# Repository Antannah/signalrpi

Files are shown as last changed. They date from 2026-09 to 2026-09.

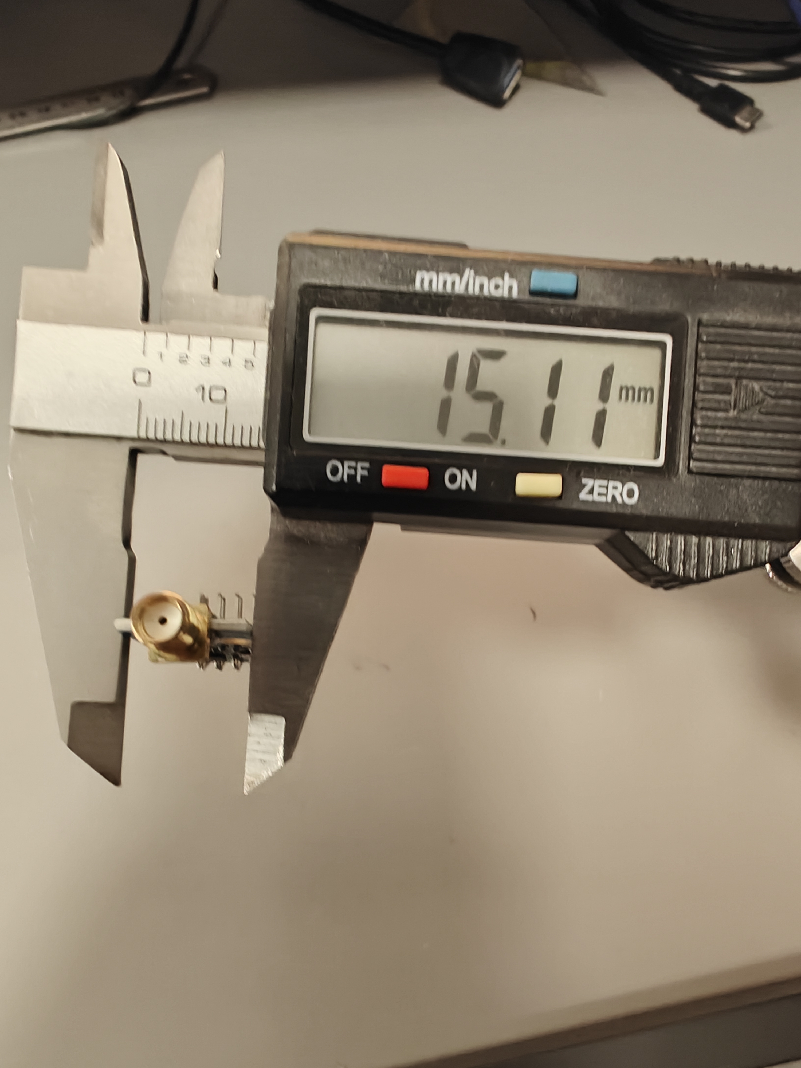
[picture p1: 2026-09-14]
doc/ebyte-07-m1101-sma_width.jpg

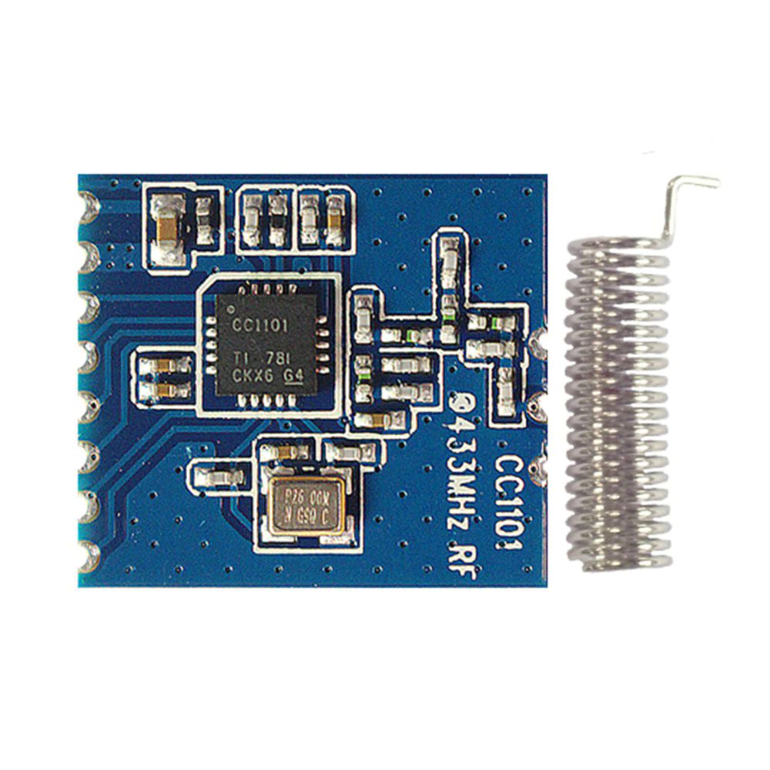
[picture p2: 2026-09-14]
doc/CC1101-433MHz-CC1101-433.png

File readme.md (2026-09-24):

# signalrpi: RF-Empfänger für Smart-Home-Komponenten (433 & 868 MHz)

Dieses Projekt realisiert einen softwarebasierten Funkempfänger für die Frequenzbänder **433 MHz** (LPD-Band) und **868 MHz** (SRD-Band) (im Kontext oft als 443 und 886 MHz referenziert). Die Hardware-Basis bildet ein **RP2040**-Microcontroller (z. B. Raspberry Pi Pico oder Pico W), an den zwei **CC1101**-Transceiver-Module direkt über SPI angebunden sind. Die Dekodierungslogik wird aus dem Open-Source-Projekt **SignalDUINO** portiert. Die dekodierten Daten oder Pulse werden über ein strukturiertes **MQTT-Protokoll** zur weiteren Verarbeitung bereitgestellt.

---

## 1. Systemarchitektur & Hardware-Topologie

Die zeitkritische Erfassung der Signalflanken (im Bereich von $100\,\mu\text{s}$ bis $1000\,\mu\text{s}$) wird direkt auf dem RP2040-Microcontroller ausgeführt. Durch die Nutzung der programmierbaren I/O-Blöcke (**PIO**) des RP2040 können die Puls- und Pausendauern deterministisch und jitterfrei erfasst werden, ohne die CPU-Kerne zu belasten.

```mermaid
graph TD
    RF433[433 MHz CC1101 Links] -->|GDO0 Pin GP6| PIO0[RP2040: PIO State Machine 0]
    RF868[868 MHz CC1101 Rechts] -->|GDO0 Pin GP21| PIO1[RP2040: PIO SM1 / FSK FIFO]
    
    RF433 <-->|SPI1 GP10-12| SPI1[RP2040: SPI1 Controller]
    RF868 <-->|SPI0 GP16/18/19| SPI0[RP2040: SPI0 Controller]
    
    PIO0 -->|Pulse Durations| CPU[RP2040: CPU Core 0/1]
    PIO1 -->|Pulse / FSK Bytes| CPU
    
    CPU -->|JSON Payloads| Comm[RP2040: WiFi CYW43439]
    Comm -->|MQTT / TCP| Broker[MQTT Broker]
```
 
### 1.1 Pin-Belegung (RP2040 zu 2× CC1101 via getrennten SPI-Bussen)

Die beiden CC1101-Module nutzen zwei **getrennte Hardware-SPI-Controller** des RP2040 (SPI1 auf der linken Pinleiste, SPI0 auf der rechten Pinleiste). Dadurch werden Buskollisionen und kapazitive Lasten auf den Leitungen vermieden.

#### Modul 1: 433 MHz Transceiver (Links, SPI1)
| CC1101 Funktion | Aderfarbe | RP2040 Pin (physisch) | RP2040 GPIO | Beschreibung |
| :--- | :--- | :--- | :--- | :--- |
| **VCC** | **Rot (rt)** | **Pin 36** | `3V3(OUT)` | Spannungsversorgung (3.3 V) |
| **GND** | **Braun (bn)** | **Pin 13** (oder 18) | `GND` | Masse |
| **SCK** | **Gelb (ge)** | **Pin 14** | `GP10 (SPI1 SCK)` | SPI Clock |
| **MOSI (SI)** | **Orange (or)** | **Pin 15** | `GP11 (SPI1 TX)` | SPI Data In (Modul) / Out (Pico) |
| **MISO (SO)** | **Grün (gn)** | **Pin 16** | `GP12 (SPI1 RX)` | SPI Data Out (Modul) / In (Pico) |
| **CSn** | **Lila (li)** | **Pin 17** | `GP13` | Chip Select Modul 1 |
| **GDO0** | **Blau (bl)** | **Pin 9** | `GP6` | Demoduliertes Signal (PIO SM0 Flankenerkennung) |
| *(GDO2)* | *(Grau/frei)* | **Pin 10** | `GP7` | Optional / Reserve |

#### Modul 2: 868 MHz Transceiver (Rechts, SPI0)
| CC1101 Funktion | Aderfarbe | RP2040 Pin (physisch) | RP2040 GPIO | Beschreibung |
| :--- | :--- | :--- | :--- | :--- |
| **VCC** | **Rot (rt)** | **Pin 36** | `3V3(OUT)` | Spannungsversorgung (3.3 V) |
| **GND** | **Braun (bn)** | **Pin 23** (oder 28/38) | `GND` | Masse |
| **MISO (SO)** | **Grün (gn)** | **Pin 21** | `GP16 (SPI0 RX)` | SPI Data Out (Modul) / In (Pico) |
| **CSn** | **Lila (li)** | **Pin 22** | `GP17` | Chip Select Modul 2 |
| **SCK** | **Gelb (ge)** | **Pin 24** | `GP18 (SPI0 SCK)` | SPI Clock |
| **MOSI (SI)** | **Orange (or)** | **Pin 25** | `GP19 (SPI0 TX)` | SPI Data In (Modul) / Out (Pico) |
| **GDO0** | **Blau (bl)** | **Pin 27** | `GP21` | Signal/Sync (PIO SM1 bei OOK oder FSK-Trigger) |
| *(GDO2)* | *(Grau/frei)* | **Pin 26** | `GP20` | Optional / Reserve |

#### Einheitliche Kabelfarbkodierung (beide Stränge)
* **VCC:** Rot (`rt`)
* **GND:** Braun (`bn`)
* **MOSI (SI):** Orange (`or`)
* **SCLK:** Gelb (`ge`)
* **MISO (SO):** Grün (`gn`)
* **GDO0:** Blau (`bl`)
* **CSn:** Lila (`li`)

#### Pufferkondensator-Konzept (bei ca. 15 cm Leitungslänge)
* **Zentraler Puffer:** $1\times 100\,\mu\text{F}$ Elektrolytkondensator direkt am Pico W zwischen `3V3(OUT)` (Pin 36) und `GND`.
* **Lokale HF-Entkopplung:** Je $1\times 10\,\mu\text{F}$ Keramikkondensator (MLCC X7R/X5R) direkt an den VCC/GND-Pins der beiden CC1101-Module am Leitungsende.

---

## 2. Frequenzbänder und HF-Modulation

Die Sensoren und Aktoren im Heimautomatisierungsbereich nutzen primär folgende Spezifikationen:

| Parameter | 433 MHz Band | 868 MHz Band |
| :--- | :--- | :--- |
| **Effektive Frequenz** | ~433.92 MHz | ~868.30 MHz |
| **Modulation** | ASK / OOK (Amplitude Shift Keying / On-Off Keying) | ASK / OOK oder FSK (Frequency Shift Keying) |
| **Typische Geräte** | Intertechno, Baumarkt-Steckdosen, Wettersensoren | MAX!, LaCrosse, HomeMatic, EQ3 |
| **Hardware-Modul** | CC1101 (konfiguriert für 433 MHz) | CC1101 (konfiguriert für 868 MHz) |

---

## 3. Funktionale Komponentenbeschreibung

Das System ist funktional in drei getrennte, sequenzielle Verarbeitungsschritte unterteilt, um eine saubere Trennung zwischen Hardware-nahem Signalempfang, logischer Dekodierung und der Verteilung der Daten zu gewährleisten.

```mermaid
graph LR
    CC1101[CC1101 Transceiver] -->|Demoduliertes Signal| Comp1[1. Signalempfang & Flankenerkennung]
    Comp1 -->|Puls-Pausen-Folge in µs| Comp2[2. Protokolldekodierung]
    Comp2 -->|Strukturierte Sensordaten| Comp3[3. MQTT-Dispatcher]
    Comp3 -->|JSON via TCP/IP| Broker[MQTT Broker]
```

---

### 3.1 Komponente 1: Empfang & Flankenerkennung (Hardware-nahe Ebene)

Diese Komponente läuft direkt auf dem **RP2040-Microcontroller**. Ihre Hauptaufgabe ist die zeitlich hochpräzise Erfassung der Phasenwechsel des demodulierten Signals am CC1101 GDO0-Pin.

#### 1. Signal-Akquisition & Demodulation (CC1101)
*   Das CC1101-Modul wird über SPI so konfiguriert, dass es das HF-Signal demoduliert (ASK/OOK oder FSK) und das binäre Basisbandsignal (High/Low) auf den GDO0-Pin legt.
*   Es erfolgt keine hardwareseitige Paketfilterung; es wird der rohe Bitstream (einschließlich Rauschen im Äther) ausgegeben.

#### 2. Jitterfreie Flankenerkennung mittels PIO (Programmable I/O)
*   Ein PIO-Programm überwacht den GPIO-Pin des GDO0-Eingangs in einer Schleife mit konstanter Taktrate (z. B. 1 MHz für eine Auflösung von $1\,\mu\text{s}$).
*   **Ablauf im PIO-Zustandsautomaten:**
    1. Warte auf Zustandsänderung (Flanke) am Pin.
    2. Wenn Flanke auftritt: Übertrage den aktuellen Zählerstand (Dauer der vorherigen Phase in $\mu\text{s}$) in die RX-FIFO des RP2040.
    3. Setze den internen Zähler zurück und beginne mit der Messung der nächsten Phase.
*   **Vorteil:** Dieses Verfahren ist deterministisch und unabhängig vom CPU-Scheduling oder Interrupt-Latenzen des Microcontrollers.

#### 3. Rauschunterdrückung & Paketabgrenzung (Software-Filterung)
*   **Glitch-Filter:** Phasen, die kürzer als eine minimale Pulsdauer sind (z. B. $< 50\,\mu\text{s}$), werden als Rauschen verworfen.
*   **Paketabgrenzung (Inter-Packet Gap):** Wenn der Pin für eine definierte Zeit (z. B. $> 5000\,\mu\text{s}$) auf einem konstanten Pegel (meist Low/Pause) bleibt, wird dies als Ende eines Datenpakets interpretiert. Die bis dahin gesammelte Puls-Pausen-Folge (ein Array aus ganzzahligen Werten in $\mu\text{s}$) wird zur Dekodierung freigegeben.

---

### 3.2 Komponente 2: Dekodierung der Signalfolgen (Mustererkennung & Protokoll-Parser)

Diese Komponente nimmt die rohe Puls-Pausen-Folge entgegen und wandelt sie in ein logisches Bit-Muster um, welches anschließend physikalisch interpretiert wird. Hierbei kommt die bewährte **SignalDUINO-Mustererkennung (`signalDecoder.cpp`)** zum Einsatz:

```mermaid
flowchart TD
    Raw["Rohe Pulsfolge (µs)"] --> PD["PatternDecoder (Mustererkennung)"]
    PD -->|"Basis-Clock T0 (z.B. 380 µs) + diskrete Vielfache [1, 3, 1, 3, 3, 1, ...]"| Decoders{"OOK-Decoder Pipeline"}
    Decoders -->|"Tri-State / Drehschalter-Code"| IT["Intertechno Decoder (V1 & V3)"]
    Decoders -->|"PWM 36-Bit Klima"| TCM["TCM97001 (NC_WS)"]
    Decoders -->|"PWM 48-Bit Bodenfeuchte"| WS["SD_WS_50"]
    Decoders -->|"Unbekanntes Muster"| Live["Live-Sniffer / Rohdaten-Export"]
```

#### 1. Dynamische Takt- und Vielfachen-Erkennung (`PatternDecoder`)
*   **Clusterung:** Bildet adaptive Cluster ähnlicher Pulslängen mit $\pm 25\%$ Toleranzband.
*   **Basis-Takt ($T_0$ / Clock):** Findet die kürzeste signifikant häufige Pulsdauer (typischerweise $10 - 15\%$ aller Pulse, z. B. $380\,\mu\text{s}$).
*   **Diskrete Vielfache:** Alle Pulse werden als ganzzahlige Vielfache quantisiert: $k_i = \text{round}(P_i / T_0)$. Dadurch sind nachgelagerte Decoder immun gegen Taktjitter und Quarzdriften.

#### 2. Protokoll-Matching & Toleranzabgleich
Die quantisierten Vielfachen werden der Kette registrierter Decoder übergeben:
*   *Tri-State Modulation:* $1T / 3T + 1T / 3T \rightarrow$ `'0'`, $1T / 3T + 3T / 1T \rightarrow$ `'F'`, $3T / 1T + 3T / 1T \rightarrow$ `'1'`, $3T / 1T + 1T / 3T \rightarrow$ `'D'`.
*   *Manchester-Codierung:* Phasenübergänge (z. B. $1T / 1T / 1T / 5T$ vs. $1T / 5T / 1T / 1T$ bei Intertechno V3).
*   *Pulsweitenmodulation (PWM):* Längenverhältnisse von High- und Low-Phasen (z. B. $1T$ High + $4T/8T$ Low bei TCM97001).

---

### 3.3 Komponente 3: MQTT-Dispatcher & Gateway (Verteilungs-Ebene)

Diese Komponente bereitet die physikalischen Daten für die Heimautomatisierung auf und sorgt für den zuverlässigen Transport über das Netzwerk.

#### 1. Payload-Strukturierung (JSON)
Die extrahierten Werte werden in eine standardisierte, maschinenlesbare JSON-Struktur überführt. Neben den Nutzdaten werden Metadaten (Zeitstempel, Signalstärke RSSI, Protokollname) angehängt, um eine lückenlose Diagnose zu ermöglichen.

#### 2. Topic-Struktur & Publish-Strategie
Die Topics sind hierarchisch aufgebaut, um eine einfache Filterung im MQTT-Broker (z. B. durch Wildcards) zu ermöglichen:
*   **Statustopic:** `signalrpi/status` (LWT - Last Will and Testament zur Verbindungsüberwachung)
*   **Raw-Topic (Debugging):** `signalrpi/raw` (Übertragung von Roh-Pulsdaten bei unbekannten Protokollen)
*   **Datentopic:** `signalrpi/messages/<protocol>/<device_id>`

#### 3. JSON-Payload-Spezifikation (Beispiel Wettersensor - Protokoll SD_WS07)
**Topic:** `signalrpi/messages/SD_WS07/sensor_ch1`
```json
{
  "timestamp": "2026-06-24T16:22:04Z",
  "protocol": "SD_WS07",
  "device_id": "sensor_ch1",
  "data": {
    "temperature": 21.4,
    "humidity": 55.0,
    "battery_low": false
  },
  "signal": {
    "rssi": -72.0,
    "pulses": 36
  }
}
```

#### 4. Integration in FHEM (via MQTT2)

FHEM-Benutzer können SignalRPI über das moderne `MQTT2`-Subsystem anbinden. Da SignalRPI standardisierte JSON-Payloads und native Status-Topics verwendet, ist kein eigener SignalDUINO-USB-Stick mehr am FHEM-Host nötig.

##### A. Broker-Verbindung herstellen (FHEM)
Falls FHEM noch nicht mit dem Mosquitto-Broker verbunden ist:
```perl
define myBroker MQTT2_CLIENT 192.168.125.4:1883
attr myBroker clientId fhem_signalrpi
attr myBroker keepalive 60
attr myBroker autocreate simple
```

##### B. Eingerichteten Sensor einbinden (`MQTT2_DEVICE`)
SignalRPI sendet Sensordaten zyklisch auf `signalrpi/devices/<ha_id>/state`. Über die FHEM-Funktion `json2nameValue($EVENT)` werden die JSON-Attribute automatisch in diskrete FHEM-Readings zerlegt:
```perl
define Blumentopf MQTT2_DEVICE
attr Blumentopf IODev myBroker
attr Blumentopf readingList signalrpi/devices/blumentopf/state:.* { json2nameValue($EVENT) }
attr Blumentopf stateFormat Feuchte: moisture % | Bat: battery_voltage V | RSSI: rssi dBm
```
*Erzeugte FHEM-Readings:* `moisture`, `battery_voltage`, `battery_low`, `adc`, `rssi`.

##### C. Schaltaktoren einbinden (Zwei-Wege-Steuerung für Licht & Steckdosen)
Für bidirektionales Schalten (Senden von Befehlen an den Pico W via `set` und automatisches Feedback via `state`):
```perl
define Tischlampe MQTT2_DEVICE
attr Tischlampe IODev myBroker
attr Tischlampe readingList signalrpi/devices/tischlampe/state:.* state
attr Tischlampe setList on:noArg signalrpi/devices/tischlampe/set ON\
                       off:noArg signalrpi/devices/tischlampe/set OFF
attr Tischlampe devStateIcon ON:on:off OFF:off:on
```

##### D. Wildcard-Lauschen auf alle Funktelegramme (SignalDUINO Roh-Ebene)
Um alle empfangenen Funktelegramme ohne manuelle Konfiguration im Web-Dashboard direkt in FHEM mitzuschneiden:
```perl
define AutoSensoren MQTT2_DEVICE
attr AutoSensoren IODev myBroker
attr AutoSensoren readingList signalrpi/messages/([^/]+)/([^/]+):.* { json2nameValue($EVENT, "$1_$2_") }
```

---

## 4. Software-Laufzeitumgebung (Entscheidung: MicroPython)

Für dieses Projekt wurde **MicroPython** als primäre Laufzeitumgebung auf dem **Raspberry Pi Pico W** ausgewählt.

### Architektur der Laufzeitumgebung

```mermaid
graph TD
    subgraph rp2040 ["RP2040 Microcontroller"]
        PIO[PIO-Zustandsmaschinen] -->|Hardware FIFO| DMA[DMA-Controller]
        DMA -->|Ringpuffer im RAM| MP[MicroPython-Laufzeit]
        MP -->|SignalDUINO-Decoder| JSON[JSON-Nachrichten]
        JSON -->|network und umqtt| WiFi[CYW43439 WiFi-Chip]
    end
    WiFi -->|MQTT via WLAN| Broker[MQTT Broker]
```

### Begründung und Funktionsweise der Arbeitsteilung:

1. **Echtzeit-Garantie über Hardware (PIO + DMA)**: 
   Die extrem zeitkritische Abtastung der Puls-Pausen-Dauern am GDO0-Pin wird vollständig in Hardware auf dem RP2040 gelöst. Die **PIO-Zustandsautomaten** messen Flankenabstände mit einer Genauigkeit von $1\,\mu\text{s}$ und schieben die Werte in eine FIFO-Queue. Ein **DMA-Kanal** schreibt diese Daten im Hintergrund direkt in einen RAM-Ringpuffer.
2. **Entkopplung vom Python-Interpreter**: 
   Da die Signal-Akquisition auf Hardware-Ebene läuft, haben eventuelle Blockaden durch die MicroPython-Laufzeitumgebung (wie z. B. Garbage Collector-Läufe oder WLAN-Sendezyklen) **keinen Einfluss** auf die Genauigkeit der Signalaufnahme. Der Ringpuffer dient als Stoßdämpfer.
3. **Effiziente Entwicklung**: 
   WLAN-Verbindung und MQTT-Publishing lassen sich in MicroPython mit sehr geringem Overhead über Standard-Bibliotheken realisieren. Die Portierung der komplexen SignalDUINO-Dekoderlogik (Perl) in lesbaren und wartbaren Python-Code beschleunigt das Projekt erheblich.

---

## 5. Inbetriebnahme, Installation & Konfiguration

Dieses Kapitel beschreibt die Erst-Inbetriebnahme eines neuen Raspberry Pi Pico W, die Dateistruktur sowie Hardware- und Test-Details.

### 6.1 Installationsvorgang (Erst-Inbetriebnahme & Schnellstart)

Dieser Abschnitt beschreibt das vollständige Aufsetzen eines fabrikneuen **Raspberry Pi Pico W** bis zum betriebsbereiten Funk-Gateway.

#### Schritt 1: MicroPython auf den Pico W aufspielen (einmalig)
Falls auf dem Pico W noch kein MicroPython installiert ist:
1. Den weißen **`BOOTSEL`**-Taster auf der Oberseite des Pico W gedrückt halten und das Board per USB an den PC anschließen.
2. Der Pico meldet sich als USB-Massenspeicher namens `RPI-RP2` an.
3. Die offizielle MicroPython `.uf2`-Firmware für den **Raspberry Pi Pico W** (empfohlen: v1.22 oder neuer) von [micropython.org/download/RPI_PICO_W](https://micropython.org/download/RPI_PICO_W/) herunterladen.
4. Die `.uf2`-Datei auf das Laufwerk `RPI-RP2` ziehen. Der Pico trennt das USB-Laufwerk automatisch, startet neu und führt ab jetzt MicroPython aus.

#### Schritt 2: Automatisches Deployment mit dem Installer (`install.py`)
1. Das Projekt-Repository auf dem PC klonen:
   ```bash
   git clone https://github.com/Antannah/signalrpi.git
   cd signalrpi
   ```
2. Den interaktiven Installer starten (erfordert Python 3 auf dem PC; `mpremote` und `pyserial` werden bei Bedarf automatisch nachinstalliert):
   ```bash
   python install.py
   ```
3. **Geführter Ablauf im Terminal:**
   * **Port-Erkennung:** Findet automatisch den angeschlossenen COM-Port des Pico W.
   * **WLAN-Abfrage:** Fragt interaktiv nach der lokalen **WLAN-SSID** und dem **WLAN-Passwort**.
   * **Asset-Kompression:** Komprimiert das Web-Dashboard mit gzip zu `src/index.html.gz` (~17 KB).
   * **Dateitransfer:** Überträgt alle Firmware-Module, Decoder und Bibliotheken sauber auf den Flash-Speicher des Pico.
   * **Neustart & IP-Ausgabe:** Startet den Pico W neu, wartet auf die Zuweisung der IP-Adresse im Heimnetz und gibt den direkten Link aus:
     ```text
     =================================================================
     🎉 INSTALLATION ERFOLGREICH!
     
     👉 Web-Dashboard erreichbar unter:  http://192.168.125.78
     
     Du kannst jetzt im Web-Dashboard unter 'System' Deine
     MQTT-Broker-Zugangsdaten eintragen und Geräte anlernen.
     =================================================================
     ```

#### Schritt 3: MQTT & Smart Home Konfiguration im Web-Dashboard
1. Öffne die im Installer angezeigte IP-Adresse im Webbrowser.
2. Wechsle auf den Tab **"System"** $\rightarrow$ **"📡 MQTT-Broker & HF-Einstellungen"**.
3. Trage die IP-Adresse Deines MQTT-Brokers (z. B. Mosquitto auf Home Assistant oder FHEM) sowie Port, optional Benutzer und Passwort ein.
4. Klicke auf **"💾 MQTT-Einstellungen speichern & neu verbinden"**. Der Pico speichert die Daten in `config.json` und verbindet sich ohne Neustart sofort mit dem Broker.

---

### 6.2 Dateistruktur auf dem Flash-Speicher

Dank der Gzip-Kompression des Web-Dashboards und der Bereinigung redundanter Module stehen **~500 KB freier Flash-Speicher** für zusätzliche Protokolle und Logs zur Verfügung:

```text
/ (Pico Flash Root)
├── boot.py               # WLAN-Start vor main.py
├── config.json           # Zentrale Konfiguration (WLAN, MQTT, RF-Modus)
├── config_loader.py      # Einheitlicher Konfigurations-Manager
├── main.py               # Hauptprogramm: Kooperative Schleife (Radio, MQTT, Web)
├── cc1101.py             # Low-Level SPI-Treiber für CC1101
├── pio_receiver.py       # PIO-State-Machine für µs-genaue OOK-Flankenerfassung
├── device_manager.py     # Geräteverwaltung, Profil-Zuweisung & HA Auto-Discovery
├── devices.json          # Persistente Konfiguration der registrierten Funkgeräte
├── web_server.py         # Asynchroner Webserver (REST-API & Gzip-Streaming)
├── index.html.gz         # Komprimiertes Web-Dashboard (~17 KB statt 74 KB)
├── time_sync.py          # NTP-Zeitsynchronisation
├── ota_updater.py        # GitHub-OTA Update-Mechanismus
├── en_decoders/          # Protokoll-Decoder und Encoder
│   ├── __init__.py       # Decoder-Registry und Dispatcher
│   ├── base.py           # Abstrakte Decoder-Basisklasse
│   ├── intertechno.py    # Intertechno V1 & V3 Decoder
│   ├── it_encoder.py     # OOK-Pulsgenerierung für Intertechno V1 / V3 TX
│   ├── pattern_decoder.py# Generischer Pattern-Decoder (Manchester, PPM etc.)
│   ├── sd_ws07.py        # Eurochron / TFA Wetterstationen
│   ├── sd_ws_fsk.py      # FSK-Wetterstationen (868 MHz)
│   ├── sd_ws_ook.py      # OOK-Wetterstationen
│   └── tcm97001.py       # TCM / Tchibo / GT-WT-02 Sensoren
└── lib/
    ├── ssl.mpy           # MicroPython SSL-Unterstützung
    └── umqtt/
        ├── simple.py     # Robuster MQTT-Client mit Keepalive und Ping
        └── simple.mpy    # Kompiliertes Bytecode-Modul
```

### 6.3 Hardware-Testaufbau & Sicherheitshinweise

Die beiden CC1101-Module werden direkt über den SPI0-Bus an den Pico W angeschlossen (siehe Belegungsplan in Kapitel 1.1).

*   **Sicherheitsregel (Antennen):** Betreibe die CC1101-Module **niemals** ohne angeschlossene Antenne. Andernfalls kann die reflektierte Sendeleistung die HF-Endstufen der Module zerstören.
    *   *433 MHz Antenne:* Drahtlänge ca. $17{,}3\,\text{cm}$ ($\lambda/4$).
    *   *868 MHz Antenne:* Drahtlänge ca. $8{,}6\,\text{cm}$ ($\lambda/4$).
*   **Spannungspegel:** Die CC1101-Module müssen mit **3.3 V** (VCC an `3V3(OUT)`) betrieben werden. Der RP2040 ist nicht 5V-tolerant.

### 6.3 Test- und Debugging-Szenarien

1.  **Decoder-Simulation (PC-basiert):**
    Die Portierung der SignalDUINO-Decoder (Perl $\rightarrow$ Python) kann vollständig offline auf dem PC getestet werden. Dazu werden aufgezeichnete Pulsfolgen (als ganzzahlige Arrays in $\mu\text{s}$) an ein Testskript auf dem PC übergeben.
2.  **Raw-Sniffing (Pico am PC):**
    Über die USB-Serial-Konsole (REPL) kann der Pico W im Sniffer-Modus betrieben werden, um unbekannte RF-Signale abzufangen und deren Pulsfolgen live im Terminal auszugeben.
3.  **End-to-End-Test:**
    Der Pico W verbindet sich autonom mit dem WLAN und sendet JSON-Telegramme an den MQTT-Broker. Zur Live-Validierung der MQTT-Payloads wird die Verwendung von **MQTT Explorer** auf dem PC empfohlen.

### 6.4 Konfiguration des 868 MHz-Empfängers

Da im 868 MHz-Band sowohl FSK-modulierte Sensoren (z. B. modernere Fine Offset/Ecowitt-Sensoren) als auch ASK/OOK-modulierte Sensoren (z. B. ältere FS20- oder MAX!-Komponenten) arbeiten, kann der Betriebsmodus für den zweiten CC1101-Transceiver in der Datei [config_local.py](file:///c:/Users/Norma/Documents/antigravity/signalrpi/src/config_local.py) konfiguriert werden:

```python
# CC1101 868 MHz Betriebsmodus
# - "FSK" : (Standard) Nutzt den CC1101-Hardware-Packet-Handler zur robusten Erfassung
#           und Filterung von FSK-Paketen (z. B. WH51, WH40).
# - "OOK" : Schaltet den Transceiver in den asynchronen Modus (Flankenerkennung per PIO),
#           um rohe ASK/OOK-Pulsfolgen wie bei 433 MHz zu erfassen.
MODE_868 = "FSK"
```

*   **Verhalten bei `"FSK"`:**
    *   Der CC1101 filtert das Signal hardwareseitig auf das Sync-Word `0x2DD4`.
    *   Valide Pakete werden per SPI-FIFO gelesen und an [decode_fsk_packet](file:///c:/Users/Norma/Documents/antigravity/signalrpi/src/en_decoders/__init__.py#L32) übergeben.
    *   Es wird keine PIO-State-Machine für diesen Empfänger belegt (Ressourceneinsparung auf dem RP2040).
*   **Verhalten bei `"OOK"`:**
    *   Der CC1101 leitet das unstrukturierte Basisbandsignal an Pin GP21 weiter.
    *   Die **PIO State Machine 1** wird gestartet, um die Impuls- und Pausendauern zu messen.
    *   Die resultierenden Pulsfolgen werden an [decode_signal](file:///c:/Users/Norma/Documents/antigravity/signalrpi/src/en_decoders/__init__.py#L46) (identisch zum 433 MHz-Pfad) übergeben.

---

## 6. Decoder-Spezifikation & Unterstützte Protokolle

Um die Kompatibilität mit Deiner bestehenden FHEM-Installation sicherzustellen, wurden die folgenden Decoder implementiert und integriert.

### 6.1 TCM97001 (TFA / NC_WS Klimasensoren)
*   **HF-Parameter:** Frequenz 433.92 MHz, Modulation ASK/OOK.
*   **Beschreibung:** Dieser Decoder übersetzt Signale von Temperatur- und Luftfeuchtigkeitssensoren (z. B. TFA Thermo-Hygrometer oder PEARL NC7159).
*   **Telegramm-Format:** 36-Bit PWM (Pulse-Width Modulation via `PatternDecoder`).
    *   *Puls-Timing:*
        *   **Sync:** ca. $500\,\mu\text{s}$ High + $9000\,\mu\text{s}$ Low.
        *   **Logisch 0:** ca. $500\,\mu\text{s}$ High + $2000\,\mu\text{s}$ Low ($1T$ High + $4T$ Low).
        *   **Logisch 1:** ca. $500\,\mu\text{s}$ High + $4000\,\mu\text{s}$ Low ($1T$ High + $8T$ Low).
    *   *Dekodierungslogik:* 
        *   Extrahiert die 12-Bit-Temperatur (Bits 16-27), wobei negative Werte im Zweierkomplement berechnet werden.
        *   Extrahiert die 7-Bit-Luftfeuchtigkeit (Bits 29-35), den Kanal (Bits 14-15), den Batteriestatus (Low = `0`, OK = `1`) und den Sendemodus.
        *   Die Geräte-ID in FHEM entspricht dem dezimalen Wert des ersten Bytes (z. B. `0x50` -> ID `80`).
*   **MQTT-Topic:** `signalrpi/messages/TCM97001/<device_id>`
*   **JSON-Payload:**
    ```json
    {
      "temperature": 21.4,
      "humidity": 55.0,
      "battery_low": false,
      "channel": 3,
      "forced_send": false
    }
    ```

### 6.2 Intertechno (IT - Funkaktoren & Fernbedienungen)
*   **HF-Parameter:** Frequenz 433.92 MHz, Modulation ASK/OOK.
*   **Beschreibung:** Steuert Funksteckdosen, Einbauschalter und empfängt Signale von Handsendern und Wandschaltern.

#### Intertechno V1 (Klassische Dreh- & DIP-Schalter)
*   **Telegramm-Format:** 12 Tri-State Bits (24 Flankenpaare + Sync-Pause).
*   **Tri-State Codierung (Basiszeit $T_0 \approx 380\,\mu\text{s}$):**
    *   `'0'`: $1T$ High, $3T$ Low, $1T$ High, $3T$ Low
    *   `'F'`: $1T$ High, $3T$ Low, $3T$ High, $1T$ Low
    *   `'1'`: $3T$ High, $1T$ Low, $3T$ High, $1T$ Low
    *   `'D'`: $3T$ High, $1T$ Low, $1T$ High, $3T$ Low
    *   **Sync-Pause:** $1T$ High, $\approx 31T$ Low (ca. $11{,}5\,\text{ms}$)
*   **Telegramm-Aufbau (nach FHEM `10_IT.pm` Drehschalter-Standard):**
    *   *Bits 0..3:* Hauscode / Family (A..P, z. B. `0F00` = `C`)
    *   *Bits 4..7:* Geräteadresse (1..16, z. B. `0F00` = `3`)
    *   *Bits 8..9:* Gruppe (`0F`)
    *   *Bits 10..11:* Zustand (`FF` = ON, `F0` = OFF)
*   **MQTT-Topic:** `signalrpi/messages/IT/<family>_<group>_<device>` (z. B. `IT/C_1_3`)
*   **JSON-Payload:**
    ```json
    {
      "family": "C",
      "group": 1,
      "device": 3,
      "state": "ON",
      "raw_tristate": "0F000F000FFF",
      "clock": 380
    }
    ```

#### Intertechno V3 (Selbstlernend / Manchester)
*   **Telegramm-Format:** 32-Bit Manchester (Preamble $1T$ High + $10T$ Low, 32 Bits, Stop-Pause $1T$ High + $36T$ Low).
*   **Codierung ($T_0 \approx 275\,\mu\text{s}$):**
    *   Bit 0: $1T$ High, $1T$ Low, $1T$ High, $5T$ Low
    *   Bit 1: $1T$ High, $5T$ Low, $1T$ High, $1T$ Low
*   **Aufbau:** 26 Bit Rolling-Code + 1 Bit Gruppe + 1 Bit State + 4 Bit Unit/Kanal.
*   **MQTT-Topic:** `signalrpi/messages/IT_V3/<binary_code>`

### 6.3 SD_WS (SignalDUINO Wettersensoren)
Dieser Decoder fasst verschiedene Wettersensoren (Bodenfeuchte und Regen) zusammen, die über das SignalDUINO-Framework empfangen werden.

#### SD_WS_50 (Bodenfeuchtesensoren / Opus XT300)
*   **HF-Parameter:** Frequenz 433.92 MHz, ASK/OOK (Pulsweiten-Modulation).
*   **Puls-Timing:**
    *   **Logisch 0:** ca. $1500\,\mu\text{s}$ High + $1000\,\mu\text{s}$ Low.
    *   **Logisch 1:** ca. $500\,\mu\text{s}$ High + $1000\,\mu\text{s}$ Low.
    *   **Paketlänge:** 48 Bits (6 Bytes), Preamble stets `0xFF`.
*   **Prüfsumme:** Summe der Bytes 1 bis 4 modulo 256 entspricht Byte 5.
*   **MQTT-Topic:** `signalrpi/messages/SD_WS_50/SM_<sensor_id>` (z. B. `SM_1`)
*   **JSON-Payload:** `{"moisture": 45.0, "temperature": 23.5}`

#### SD_WS_107 (Eurochron Bodenfeuchtesensoren / Fine Offset WH51)
*   **HF-Parameter:** Frequenz 868.30 MHz, Modulation 2-FSK (Paketmodus).
*   **Hardware-Empfang:** CC1101 synchronisiert auf das Sync-Word `2DD4`, filtert nach Paketlänge (14 Bytes Payload) und reicht die Bytes per SPI weiter.
*   **Validierung:** 
    *   Prüft auf Family-Code `0x51`.
    *   Prüft CRC8 (Polynom `0x31`, Startwert `0x00`) über Byte 0-11 gegen Byte 12.
    *   Prüft Sum-8 Checksumme über Byte 0-12 gegen Byte 13.
*   **MQTT-Topic:** `signalrpi/messages/SD_WS_107/<device_id>` (z. B. `0D32C1`)
*   **JSON-Payload:** `{"moisture": 62.0, "battery_voltage": 1.6, "battery_low": false, "adc": 199}`

#### SD_WS_126 (Bresser/Ecowitt Regensensor WH40)
*   **HF-Parameter:** Frequenz 868.30 MHz, Modulation 2-FSK (Paketmodus).
*   **Hardware-Empfang:** CC1101 synchronisiert auf das Sync-Word `2DD4`, filtert nach Paketlänge (14 Bytes Payload).
*   **Validierung:**
    *   Prüft auf Family-Code `0x40`.
    *   Prüft CRC8 (Polynom `0x31`, Startwert `0x00`) über Byte 0-6 gegen Byte 7.
    *   Prüft Sum-8 Checksumme über Byte 0-7 gegen Byte 8.
*   **MQTT-Topic:** `signalrpi/messages/SD_WS_126/<device_id>` (z. B. `011CDF`)
*   **JSON-Payload:** `{"rain_total": 12.3, "rain_ticks": 123, "battery_voltage": 1.5, "battery_low": false}`

---

## 7. Lizenz & Danksagungen (Acknowledgements)

Dieses Projekt ist unter der **GNU General Public License v3.0 (GPLv3)** lizenziert. Siehe [LICENSE](LICENSE) für den vollständigen Lizenztext.

### Danksagung
Ein herzlicher Dank geht an die Open-Source-Community rund um das FHEM- und RF-Ökosystem, insbesondere an das Team von **[RFD-FHEM](https://github.com/RFD-FHEM)**:
*   **[SignalDUINO](https://github.com/RFD-FHEM/RFFHEM)** / **[RFFHEM](https://github.com/RFD-FHEM/RFFHEM)**: Für die Pionierarbeit bei der Erfassung, Dokumentation und Dekodierung zahlloser 433- und 868-MHz-Funkprotokolle.

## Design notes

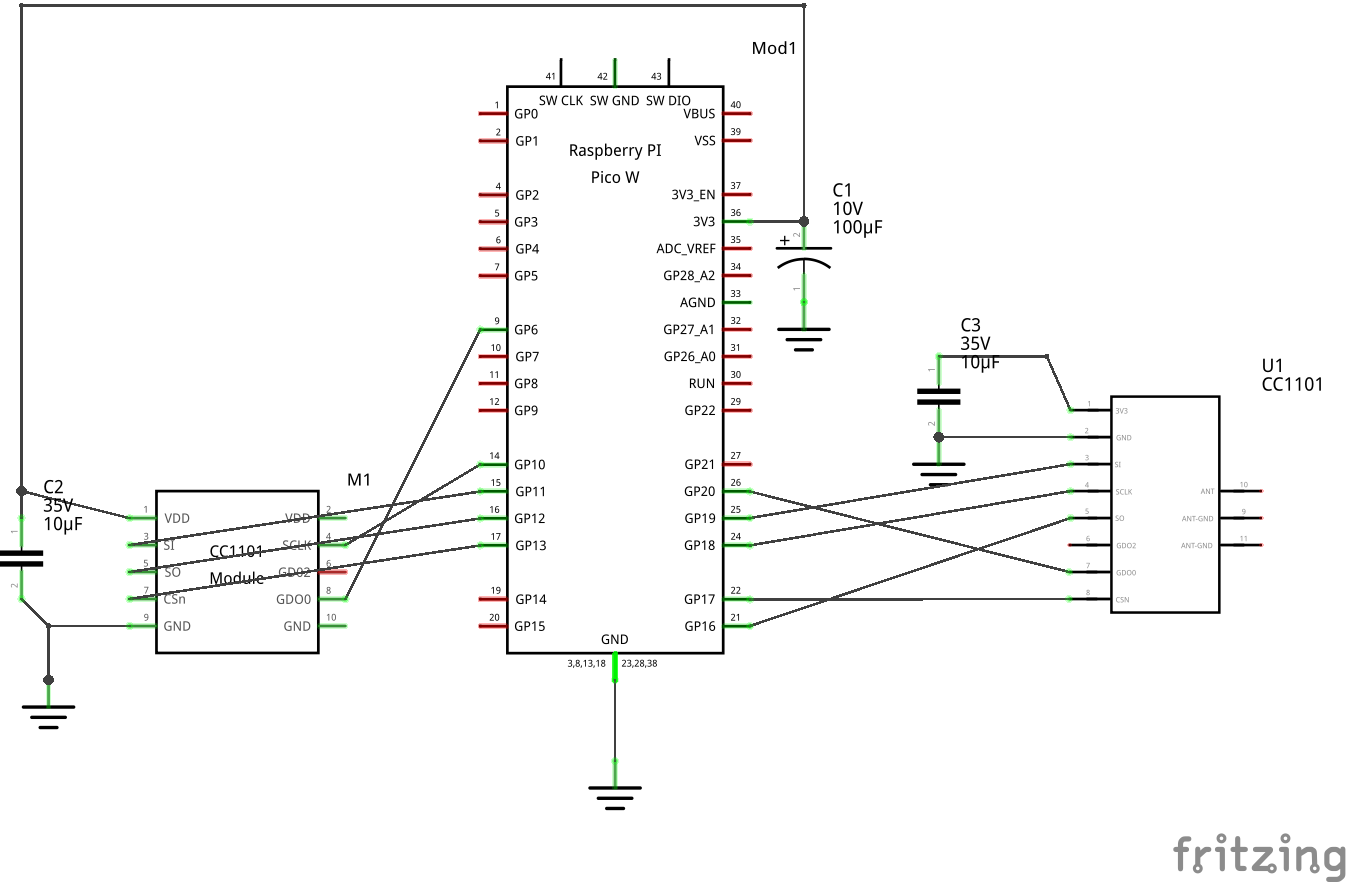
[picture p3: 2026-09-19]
doc/signalrpi_Schaltplan.png

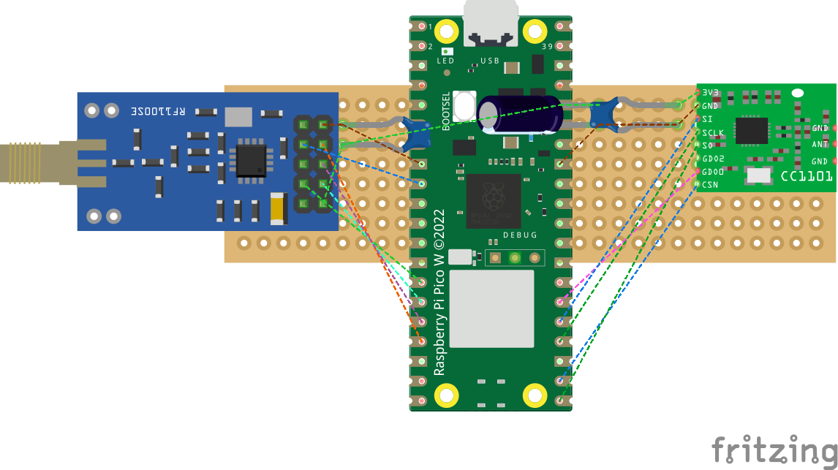
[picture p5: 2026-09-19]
doc/signalrpi_Steckbrett.png

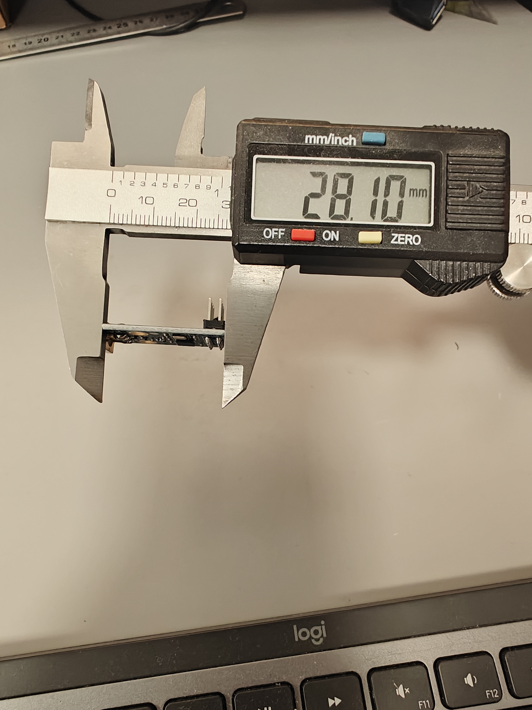
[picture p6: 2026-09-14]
doc/ebyte-07-m1101-sma_length.jpg

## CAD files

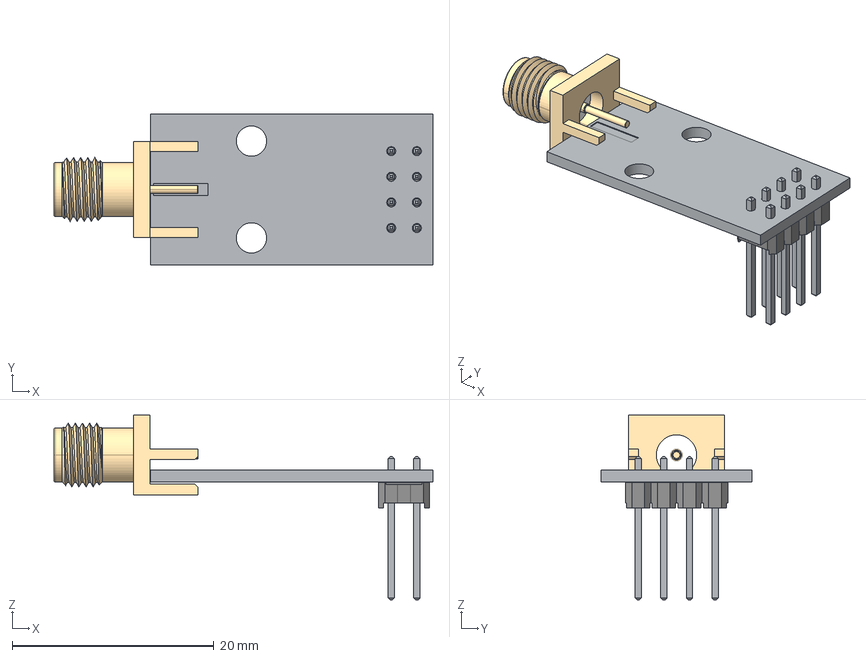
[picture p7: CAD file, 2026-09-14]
doc/ebyte-e07-m1101d-sma-1.snapshot.7/ebyte_e07-m1101d-sma.step
37.6 x 15.0 x 18.3 mm
ebyte_pcb
??????????_???????_005
??????????_???????_006
??????????_???????001
??????????_???????_007
13mm_pinheader_009
13mm_pinheader_010
13mm_pinheader_011
13mm_pinheader_012
13mm_pinheader_013
13mm_pinheader_014
13mm_pinheader_015
13mm_pinheader_016

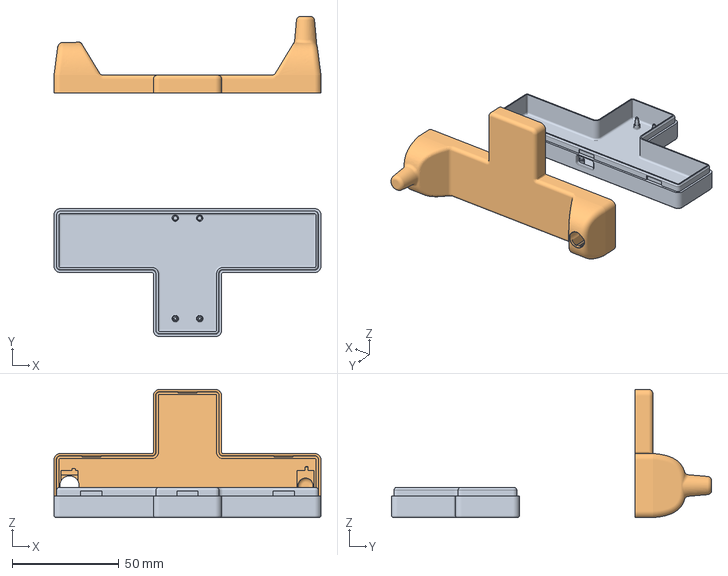
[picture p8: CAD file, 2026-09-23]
doc/Gehaeuse.3mf
125.0 x 150.0 x 60.0 mm
signalrpi-gehaeuse-Gehaeuse.step
signalrpi-gehaeuse-Deckel.step

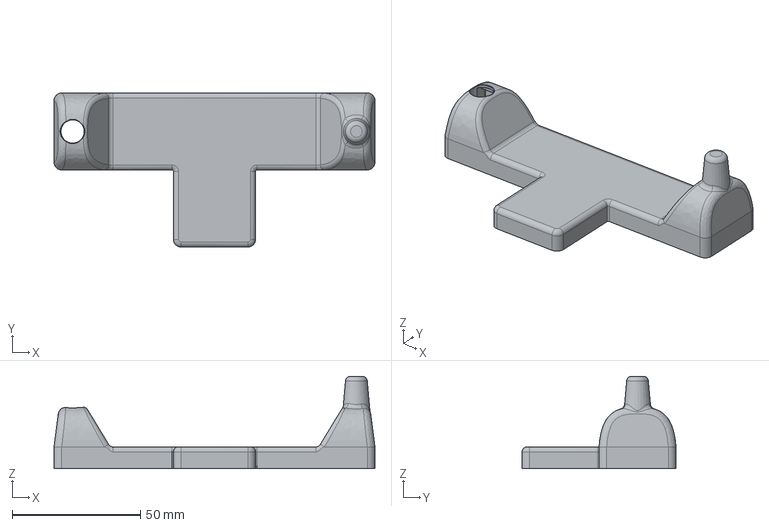
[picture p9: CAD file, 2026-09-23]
doc/signalrpi-gehaeuse-Deckel.step
125.0 x 60.0 x 36.0 mm

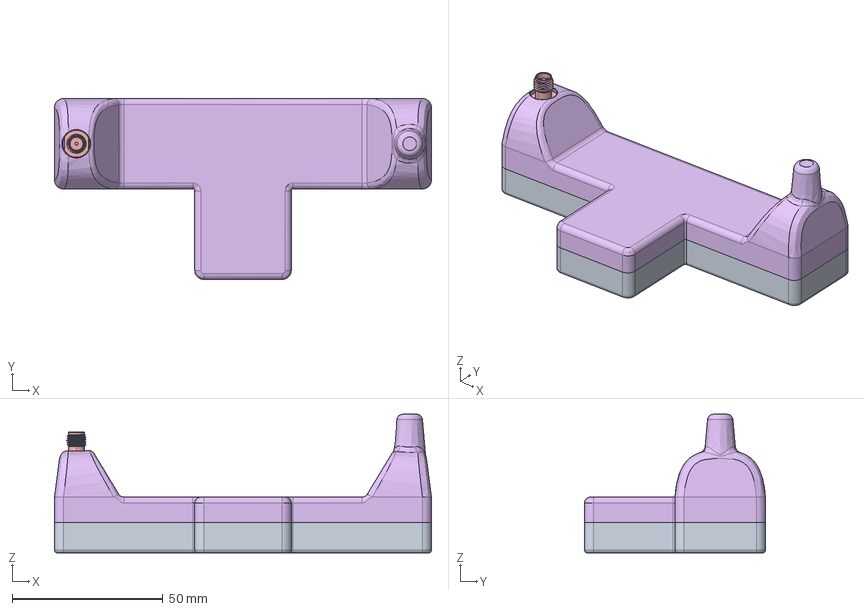
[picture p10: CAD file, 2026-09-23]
doc/signalrpi-gehaeuse.FCStd
125.0 x 60.0 x 46.0 mm
Gehaeuse
PICO_REF_BOARD.STEP
PICO_REF_USB.STEP
PICO_REF_SWITCH.STEP
PICO_REF_MICROCONTROLLER.STEP
PICO_REF_LED.STEP
PICO_REF_ONSEMI.STEP
PICO_BOURNS.STEP
PICO_MURATA.STEP
PICO_MURATA.STEP001
PICO_RICHTEK.STEP
PICO_DIODES.STEP
PICO_AEL.STEP
PICO_WINBOND.STEP
??????????_???????_005
??????????_???????_006
??????????_???????001
??????????_???????_007
13mm_pinheader_009
13mm_pinheader_010
13mm_pinheader_011
13mm_pinheader_012
13mm_pinheader_013
13mm_pinheader_014
13mm_pinheader_015
13mm_pinheader_016
Deckel
R_0402_1005Metric
R_0402_1005Metric001
L_0402_1005Metric
L_0402_1005Metric001
L_0402_1005Metric002
L_0402_1005Metric003
C_0402_1005Metric
C_0402_1005Metric_X7R_0
C_0402_1005Metric002
C_0402_1005Metric003
C_0402_1005Metric004
C_0402_1005Metric005
C_0402_1005Metric006
C_0402_1005Metric007
C_0402_1005Metric008
C_0402_1005Metric009
C_0402_1005Metric010
C_0402_1005Metric_X7R_001
C_0402_1005Metric_X7R_002
C_0402_1005Metric_X7R_003
C_0402_1005Metric_X7R_004
C_0603_1608Metric
Texas_S_PVQFN_N20_EP24x24mm
Crystal_SMD_SeikoEpson_FA238-4Pin_3.2x2.5mm

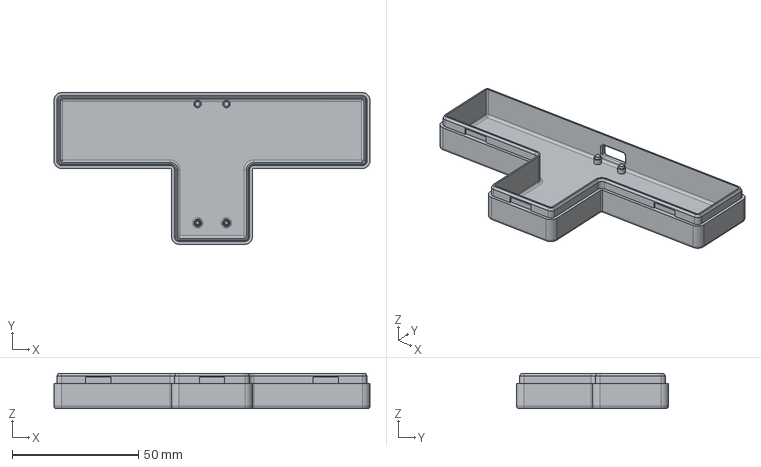
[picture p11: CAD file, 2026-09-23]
doc/signalrpi-gehaeuse-Gehaeuse.step
125.0 x 60.0 x 14.0 mm

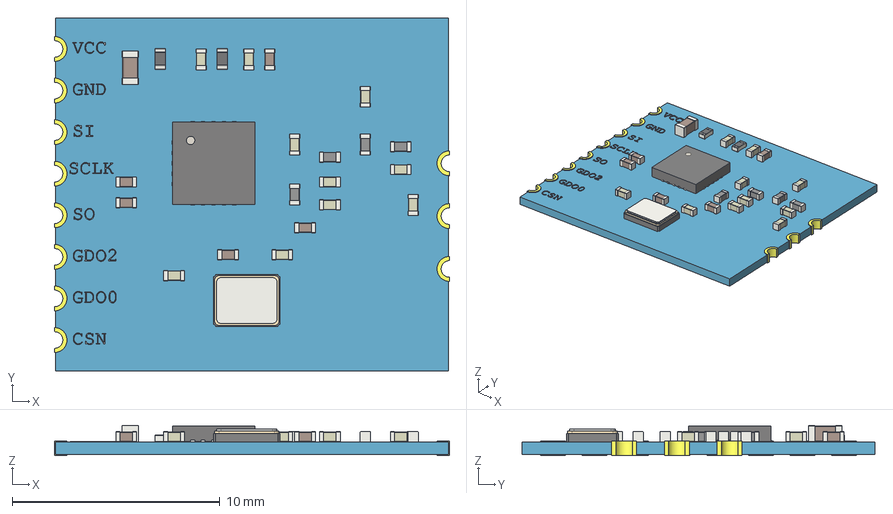
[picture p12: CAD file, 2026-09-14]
doc/module_CC1101_t.step
19.0 x 17.0 x 1.45 mm
R_0402_1005Metric
R_0402_1005Metric001
L_0402_1005Metric
L_0402_1005Metric001
L_0402_1005Metric002
L_0402_1005Metric003
C_0402_1005Metric
C_0402_1005Metric_X7R_0
C_0402_1005Metric002
C_0402_1005Metric003
C_0402_1005Metric004
C_0402_1005Metric005
C_0402_1005Metric006
C_0402_1005Metric007
C_0402_1005Metric008
C_0402_1005Metric009
C_0402_1005Metric010
C_0402_1005Metric_X7R_001
C_0402_1005Metric_X7R_002
C_0402_1005Metric_X7R_003
C_0402_1005Metric_X7R_004
C_0603_1608Metric
Texas_S_PVQFN_N20_EP24x24mm
Crystal_SMD_SeikoEpson_FA238-4Pin_3.2x2.5mm

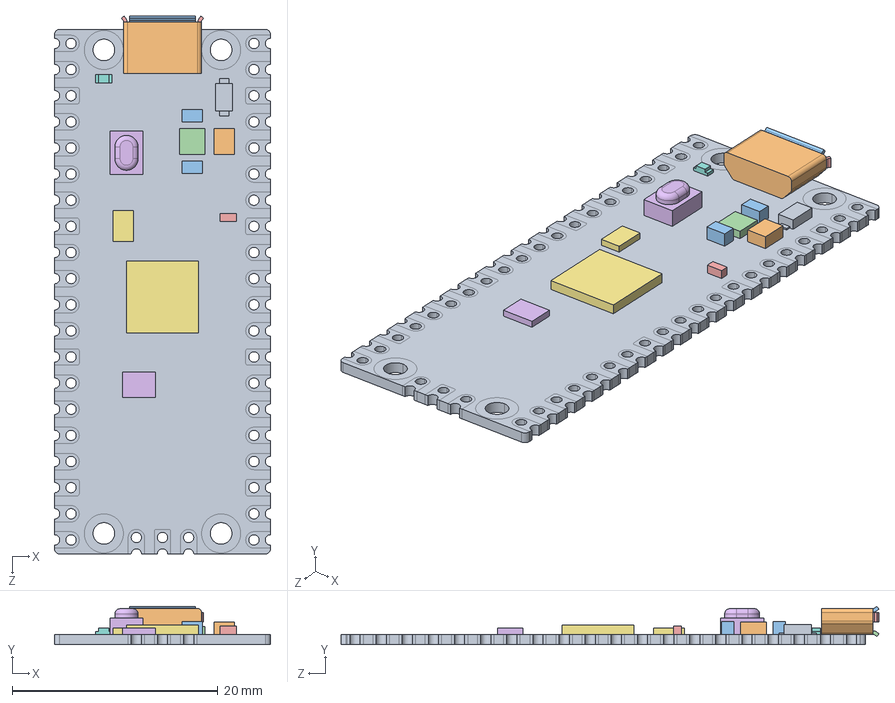
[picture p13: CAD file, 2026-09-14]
doc/Pico-R3.step
21.0 x 3.73 x 52.3 mm
PICO_REF_BOARD.STEP
PICO_REF_USB.STEP
PICO_REF_SWITCH.STEP
PICO_REF_MICROCONTROLLER.STEP
PICO_REF_LED.STEP
PICO_REF_ONSEMI.STEP
PICO_BOURNS.STEP
PICO_MURATA.STEP x 2
PICO_RICHTEK.STEP
PICO_DIODES.STEP
PICO_AEL.STEP
PICO_WINBOND.STEP

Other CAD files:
doc/ebyte_e07-m1101d-sma.step

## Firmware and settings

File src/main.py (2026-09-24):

# main.py -- Hauptprogramm
# Empfängt Pulsfolgen und verteilt diese über MQTT.

import machine
import time
import json
import gc
from machine import Pin, SPI

# RT6150-Schaltregler des Pico in den PWM-Modus (CCM) zwingen.
# Im Standard-PSM (PFM) schwingt die Schaltfrequenz lastabhängig und erzeugt
# auf der 3V3-Schiene einen Ripple von 50–150 mV, der den CC1101 LNA/VCO stört.
# Mit GPIO23 = HIGH: feste Taktung → Ripple < 10 mV.
_smps_mode = machine.Pin(23, machine.Pin.OUT)
_smps_mode.value(1)
from cc1101 import CC1101
from pio_receiver import PIOReceiver
from umqtt.simple import MQTTClient
import en_decoders as decoders

# Onboard-LED für Aktivitätsanzeige (Pico W nutzt Pin 'LED' über den CYW43)
try:
    led = Pin("LED", Pin.OUT)
    led.value(0)
except Exception:
    led = None

# Versuche, die Konfiguration aus config_loader (config.json) oder config_local zu laden
try:
    from config_loader import config
    has_config = True
except Exception:
    try:
        import config_local as config
        has_config = True
    except ImportError:
        print("Fehler: Weder config.json noch config_local.py gefunden.")
        has_config = False

if has_config:
    # 1. SPI-Busse für CC1101-Module initialisieren (2 getrennte Hardware-Controller)
    # SPI1 (Links): GP10 = SCK, GP11 = MOSI, GP12 = MISO
    # SPI-Takt auf 1 MHz reduziert: reicht für CC1101-Register/FIFO vollständig aus.
    # 5 MHz erzeugte Oberwellen bei 10/15/20 MHz, die direkt in den 10,7-MHz-ZF-Pfad des CC1101 einstrahlten.
    spi1 = SPI(1, baudrate=1_000_000, polarity=0, phase=0, sck=Pin(10), mosi=Pin(11), miso=Pin(12))
    # SPI0 (Rechts): GP18 = SCK, GP19 = MOSI, GP16 = MISO
    spi0 = SPI(0, baudrate=1_000_000, polarity=0, phase=0, sck=Pin(18), mosi=Pin(19), miso=Pin(16))
    
    # 2. CC1101-Module instanziieren
    # CC1101 #1 für 433 MHz (Links): SPI1, CS = GP13, GDO0 = GP6
    cc_433 = CC1101(spi1, cs_pin=Pin(13), gdo0_pin=Pin(6))
    # CC1101 #2 für 868 MHz (Rechts): SPI0, CS = GP17, GDO0 = GP21
    cc_868 = CC1101(spi0, cs_pin=Pin(17), gdo0_pin=Pin(21))
    
    # Betriebsmodus für 868 MHz konfigurieren (Standard: FSK)
    mode_868 = getattr(config, "MODE_868", "FSK").upper()
    
    # Globaler Alert-Puffer für System-Ereignisse (max. 20)
    system_alerts = []

    def push_alert(level: str, msg: str):
        t = time.localtime()
        time_str = "{:02d}:{:02d}:{:02d}".format(t[3], t[4], t[5])
        if len(system_alerts) > 20:
            system_alerts.pop(0)
        entry = {"time": time_str, "level": level, "msg": msg}
        system_alerts.append(entry)
        print(f"[{level.upper()}] {msg}")

    print("Initialisiere HF-Empfänger...")
    cc_433.init_ask_ook(433.92)
    
    # 3. PIO-Receiver für die Flankenerkennung instanziieren
    # State Machine 0 für 433 MHz (GDO0 an GP6)
    rx_433 = PIOReceiver(sm_id=0, pin_num=6)
    
    if mode_868 == "FSK":
        print("868 MHz Empfänger im FSK-Paketmodus (868.30 MHz) initialisiert.")
        cc_868.init_fsk_packet(868.30)
        rx_868 = None
    else:
        print("868 MHz Empfänger im OOK-Modus (asynchron) initialisiert.")
        cc_868.init_ask_ook(868.30)
        # State Machine 1 für 868 MHz (GDO0 an GP21)
        rx_868 = PIOReceiver(sm_id=1, pin_num=21)

    # Hardware-Selbsttest beider CC1101-Module
    hw_433 = cc_433.check_hardware()
    hw_868 = cc_868.check_hardware()
    
    if hw_433["ok"]:
        push_alert("info", f"CC1101 433 MHz bereit: {hw_433['msg']}")
    else:
        push_alert("error", f"CC1101 433 MHz FEHLER: {hw_433['msg']}")
        
    if hw_868["ok"]:
        push_alert("info", f"CC1101 868 MHz bereit: {hw_868['msg']}")
    else:
        push_alert("error", f"CC1101 868 MHz FEHLER: {hw_868['msg']}")
    
    # 4. WLAN-Verbindung herstellen
    import network
    # Hostname für DHCP / Fritzbox setzen (muss vor active/connect passieren)
    try:
        network.hostname("SignalRPI")
    except Exception:
        pass
    wlan = network.WLAN(network.STA_IF)
    wlan.active(True)
    try:
        wlan.config(hostname="SignalRPI")
    except Exception:
        pass
    if not wlan.isconnected():
        print("Verbinde mit WLAN '{}'...".format(config.WIFI_SSID))
        wlan.connect(config.WIFI_SSID, config.WIFI_PASSWORD)
        timeout = 25
        while not wlan.isconnected() and timeout > 0:
            time.sleep(0.5)
            timeout -= 1
            
    if wlan.isconnected():
        ip = wlan.ifconfig()[0]
        print("WLAN erfolgreich verbunden! IP-Adresse:", ip)
        # NTP Zeitsynchronisation
        try:
            import time_sync
            time_sync.sync_time(wlan)
        except Exception as e:
            print("Zeitsynchronisations-Fehler:", e)
    else:
        print("Warnung: WLAN-Verbindung fehlgeschlagen!")

    # 5. Device Manager vorbereiten
    from device_manager import DeviceManager
    device_mgr = DeviceManager()

    # 6. Sende-Handler für 433 MHz (Intertechno V1 & V3)
    from en_decoders.it_encoder import ITEncoder

    def handle_tx(cmd_data: dict) -> bool:
        """
        Führt einen Sende-Befehl über das 433 MHz CC1101-Modul aus.
        Unterstützt Intertechno V1 und V3 mit konfigurierbaren Wiederholungen (repetitions).
        """
        try:
            proto = cmd_data.get("protocol", "IT_V3").upper()
            action = cmd_data.get("action", "on").lower()
            state = (action in ["on", "learn", "true", "1"])
            reps = int(cmd_data.get("repetitions", 6))
            
            pulses = None
            if proto == "IT_V3":
                bin_code = cmd_data.get("binary_code", "00011100110111100110100111")
                channel = int(cmd_data.get("channel", 1))
                pulses = ITEncoder.encode_it_v3(bin_code, channel, state, group=False)
            elif proto in ["IT", "IT_V1"]:
                fam = cmd_data.get("family", "A")
                group = int(cmd_data.get("group", 1))
                dev = int(cmd_data.get("device", 1))
                pulses = ITEncoder.encode_it_v1(fam, group, dev, state)
                
            if pulses:
                # Vorübergehend State Machine von RX pausieren während TX
                rx_433.sm.active(0)
                try:
                    cc_433.transmit_ook_pulses(cc_433.gdo0_pin, pulses, repetitions=reps)
                finally:
                    # RX-FIFO leeren, um eigene TX-Signale zu verwerfen
                    while rx_433.sm.rx_fifo() > 0:
                        rx_433.sm.get()
                    rx_433.pulse_buffer.clear()
                    rx_433.expect_high = True
                    rx_433.sm.active(1)
                print("TX 433 MHz:", proto, action.upper(), "Reps:", reps)
                return True
        except Exception as ex:
            print("Fehler beim 433 MHz Senden:", ex)
        return False

    # 7. MQTT-Client Manager mit robuster Resubscription und Auto-Reconnect
    client = None
    last_mqtt_reconnect = 0
    last_mqtt_ping = time.time()

    def mqtt_callback(topic, msg):
        try:
            t_str = topic.decode("utf-8") if isinstance(topic, bytes) else str(topic)
            m_str = msg.decode("utf-8").strip() if isinstance(msg, bytes) else str(msg).strip()
            print("[MQTT IN] Topic:", t_str, "Payload:", m_str)
            
            if t_str == "signalrpi/system/ota_update":
                branch = m_str if m_str and not m_str.startswith("{") else "main"
                if m_str.startswith("{"):
                    try:
                        b_data = json.loads(m_str)
                        branch = b_data.get("branch", "main")
                    except Exception:
                        pass
                print("MQTT OTA Update Befehl empfangen für Branch:", branch)
                import ota_updater
                ota_updater.update_from_github(branch=branch)
                
            elif t_str.startswith("signalrpi/devices/") and t_str.endswith("/set"):
                # Format: signalrpi/devices/<ha_id>/set
                parts = t_str.split("/")
                ha_id = parts[2]
                dev = device_mgr.get_device(ha_id)
                d_type = dev.get("profile") or dev.get("type") if dev else None
                if dev and d_type in ["switch", "light"]:
                    reps = dev.get("repetitions", 6)
                    proto = dev.get("protocol", "IT_V3")
                    state_val = m_str.upper()
                    tx_cmd = {
                        "protocol": proto,
                        "action": "on" if state_val in ["ON", "TRUE", "1"] else "off",
                        "repetitions": reps
                    }
                    if proto == "IT_V3":
                        tx_cmd["binary_code"] = dev.get("binary_code")
                        tx_cmd["channel"] = dev.get("channel", 1)
                    elif proto in ["IT", "IT_V1"]:
                        it_c = dev.get("it_code", {})
                        tx_cmd["family"] = it_c.get("family", "A")
                        tx_cmd["group"] = it_c.get("group", 1)
                        tx_cmd["device"] = it_c.get("device", 1)
                        
                    print("MQTT Befehl für {}: {} ({})".format(ha_id, tx_cmd["action"], proto))
                    if handle_tx(tx_cmd):
                        # Schalter-/Licht-Status an Home Assistant zurückmelden
                        if client:
                            client.publish("signalrpi/devices/{}/state".format(ha_id), state_val, retain=True)
                        device_mgr.set_latest(ha_id, {"state": state_val})
                        
            elif t_str.startswith("signalrpi/devices/") and t_str.endswith("/repetitions/set"):
                # Format: signalrpi/devices/<ha_id>/repetitions/set
                parts = t_str.split("/")
                ha_id = parts[2]
                try:
                    new_rep = int(m_str)
                    device_mgr.set_repetitions(ha_id, new_rep)
                    print("MQTT Repetitions für", ha_id, "auf", new_rep, "gesetzt")
                except Exception as e:
                    print("Fehler beim Setzen der Repetitions:", e)
        except Exception as ex:
            print("MQTT Callback Fehler:", ex)

    def ensure_mqtt_subscribed():
        global client, last_mqtt_reconnect, last_mqtt_ping
        if not wlan.isconnected():
            return False
            
        now = time.time()
        # Mindestens 5 Sekunden zwischen Reconnect-Versuchen warten
        if client is not None and (now - last_mqtt_reconnect) < 5:
            return False

        last_mqtt_reconnect = now
        try:
            if client is None:
                client = MQTTClient(
                    config.MQTT_CLIENT_ID,
                    config.MQTT_BROKER,
                    port=config.MQTT_PORT,
                    user=config.MQTT_USER,
                    password=config.MQTT_PASSWORD,
                    keepalive=60
                )
                client.set_last_will("signalrpi/status", '{"state": "offline"}', retain=True, qos=1)
                client.set_callback(mqtt_callback)
            
            # Neu verbinden
            try:
                client.disconnect()
            except Exception:
                pass
            client.connect()
            
            # Subscriptions nach jedem Reconnect neu registrieren
            client.subscribe("signalrpi/system/ota_update")
            client.subscribe("signalrpi/devices/+/set")
            client.subscribe("signalrpi/devices/+/repetitions/set")
            
            # Status online melden
            client.publish("signalrpi/status", '{"state": "online"}', retain=True, qos=1)
            client.publish("signalrpi/status/hardware", json.dumps({"cc_433": hw_433, "cc_868": hw_868}), retain=True)
            
            # Device Manager mit Client verknüpfen
            device_mgr.mqtt_client = client
            print("MQTT erfolgreich verbunden und Subscriptions registriert!")
            last_mqtt_ping = time.time()
            return True
        except Exception as e:
            print("MQTT Verbindungs-/Subscription-Fehler:", e)
            client = None
            device_mgr.mqtt_client = None
            return False

    # Initiale MQTT-Verbindung
    print("Verbinde mit MQTT-Broker: {}...".format(config.MQTT_BROKER))
    ensure_mqtt_subscribed()

    # Puffer für Live-Sniffer im Webinterface (max 30 Pakete)
    sniffer_queue = []

    def push_sniffer(band, proto, dev_id, rssi, data=None, channel=None, matched_name=None, raw_data=None, ms_pattern=None):
        if len(sniffer_queue) > 30:
            sniffer_queue.pop(0)
        t = time.localtime()
        time_str = "{:02d}:{:02d}:{:02d}".format(t[3], t[4], t[5])
        sniffer_queue.append({
            "time": time_str,
            "band": band,
            "proto": proto,
            "id": dev_id,
            "channel": channel,
            "rssi": round(rssi, 1),
            "data": data or {},
            "device_name": matched_name,
            "raw": raw_data,
            "ms": ms_pattern
        })

    # 8. Asynchroner Webserver starten
    import gc
    gc.collect()
    import uasyncio as asyncio
    from web_server import WebServer
    web_srv = WebServer(device_manager=device_mgr, sniffer_queue=sniffer_queue, wlan=wlan, port=80, tx_handler=handle_tx)
    web_srv.cc_433 = cc_433
    web_srv.cc_868 = cc_868
    web_srv.alerts = system_alerts
    web_srv.push_alert = push_alert

    print("\nsignalrpi ist betriebsbereit!")
    if wlan.isconnected():
        print("-> Web-Dashboard erreichbar unter: http://{}".format(wlan.ifconfig()[0]))
    print("-> Starte asynchrone Tasks (Funkempfang, MQTT, Web)...")

    async def radio_loop():
        global client, last_mqtt_ping
        gc_counter = 0
        while True:
            # Während eines OTA-Updates Funk- und MQTT-Aktivität pausieren (schützt vor TLS ENOMEM)
            import ota_updater
            if ota_updater.is_updating:
                del sniffer_queue[:]
                gc.collect()
                await asyncio.sleep_ms(500)
                continue

            # 1. WLAN Überwachung & Auto-Reconnect
            if not wlan.isconnected():
                try:
                    wlan.connect(config.WIFI_SSID, config.WIFI_PASSWORD)
                except Exception:
                    pass

            # 2. MQTT Verbindung sicherstellen
            if client is None and wlan.isconnected():
                ensure_mqtt_subscribed()

            # 3. Eventuelle MQTT-Nachrichten abfragen & Keepalive-Ping
            if client:
                try:
                    client.check_msg()
                    # Regelmäßiger MQTT-Ping alle 20 Sekunden
                    now = time.time()
                    if (now - last_mqtt_ping) > 20:
                        client.ping()
                        last_mqtt_ping = now
                except Exception as ex:
                    print("[MQTT] Verbindungsfehler bei check_msg / ping:", ex)
                    client = None
                    device_mgr.mqtt_client = None
                    # Sofortiger Reconnect-Versuch inklusive Subscriptions
                    ensure_mqtt_subscribed()

            # 433 MHz Paketprüfung
            packet_433 = rx_433.get_packet()
            if packet_433:
                if led:
                    led.value(1)
                rssi = cc_433.get_rssi()
                decoded = decoders.decode_signal(packet_433)
                
                matched_ha_id, matched_name, is_enabled = (None, None, False)
                if decoded:
                    matched_ha_id, matched_name, is_enabled = device_mgr.match_and_get_info(decoded)
                    
                proto_name = decoded["protocol"] if decoded else "RAW_433"
                dev_id_str = str(decoded["device_id"]) if decoded else "-"
                ch = decoded.get("data", {}).get("channel") if decoded else None
                ms_str = decoded.get("ms_string") if decoded else None
                if not ms_str:
                    try:
                        pat = decoders.PatternDecoder.decode_pattern(packet_433)
                        if pat:
                            ms_str = pat.to_ms_string()
                    except Exception:
                        pass
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

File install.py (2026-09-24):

#!/usr/bin/env python3
"""
install.py -- Interaktiver Installer für signalrpi auf dem Raspberry Pi Pico W

Workflow:
1. Prüft / installiert Voraussetzungen (mpremote).
2. Findet den angeschlossenen Raspberry Pi Pico W am USB/COM-Port.
3. Fragt interaktiv nach den WLAN-Zugangsdaten (SSID & Passwort).
4. Erzeugt die initiale Konfigurationsdatei (config.json) auf dem Pico.
5. Überträgt alle Firmware- und Web-Dateien (mit gzip-optimiertem Frontend).
6. Startet den Pico neu und gibt die IP-Adresse des Web-Dashboards aus.
"""

import sys
import os
import time
import json
import subprocess
import glob

def print_banner():
    print("=" * 65)
    print("        📻 signalrpi -- Raspberry Pi Pico W Installer        ")
    print("       Zwei-Kanal 433 / 868 MHz Funk-Gateway fuer Smart Home   ")
    print("=" * 65)
    print()

def ensure_dependencies():
    try:
        import serial.tools.list_ports
    except ImportError:
        print("[INFO] Installiere pyserial...")
        subprocess.check_call([sys.executable, "-m", "pip", "install", "pyserial"])
    
    try:
        subprocess.run([sys.executable, "-m", "mpremote", "version"],
                       stdout=subprocess.PIPE, stderr=subprocess.PIPE, check=True)
    except Exception:
        print("[INFO] Installiere mpremote...")
        subprocess.check_call([sys.executable, "-m", "pip", "install", "mpremote"])

def find_pico_port():
    import serial.tools.list_ports
    ports = list(serial.tools.list_ports.comports())
    pico_ports = []
    
    for p in ports:
        desc = (p.description or "").lower()
        hwid = (p.hwid or "").lower()
        # Raspberry Pi Pico Vendor-ID: 2E8A
        if "2e8a" in hwid or "pico" in desc or "micropython" in desc:
            pico_ports.append(p.device)
            
    if pico_ports:
        return pico_ports[0]
    elif len(ports) == 1:
        return ports[0].device
    elif len(ports) > 1:
        print("Mehrere serielle Schnittstellen gefunden:")
        for idx, p in enumerate(ports):
            print(f"  [{idx + 1}] {p.device} ({p.description})")
        sel = input("Waehle den Port des Pico W [1]: ").strip()
        idx = int(sel) - 1 if sel.isdigit() else 0
        return ports[idx].device
    return None

def run_mpremote(port, args):
    cmd = [sys.executable, "-m", "mpremote", "connect", port] + args
    res = subprocess.run(cmd, stdout=subprocess.PIPE, stderr=subprocess.PIPE, text=True)
    return res.returncode == 0, res.stdout, res.stderr

def main():
    print_banner()
    ensure_dependencies()
    
    # 1. Port suchen
    print("[1/5] Suche angeschlossenen Raspberry Pi Pico W...")
    port = find_pico_port()
    if not port:
        print("FEHLER: Kein Raspberry Pi Pico gefunden!")
        print("Bitte verbinde den Pico W per USB-Kabel und starte install.py erneut.")
        sys.exit(1)
    print(f"      Gefunden an Port: {port}\n")

    # 2. WLAN-Zugangsdaten abfragen
    print("[2/5] WLAN-Konfiguration")
    print("      Damit der Pico W sich mit Deinem Heimnetzwerk verbinden kann:")
    
    # Prüfe ob config_local oder lokale config existiert als Vorgabe
    default_ssid = ""
    if os.path.exists("src/config_local.py"):
        try:
            with open("src/config_local.py", "r") as f:
                for line in f:
                    if "WIFI_SSID" in line and "=" in line:
                        default_ssid = line.split("=")[1].strip().strip('"').strip("'")
        except Exception:
            pass

    if default_ssid:
        ssid = input(f"      WLAN SSID [{default_ssid}]: ").strip() or default_ssid
    else:
        ssid = input("      WLAN SSID: ").strip()
        while not ssid:
            ssid = input("      WLAN SSID (Pflichtfeld): ").strip()

    wifi_pass = input("      WLAN Passwort: ").strip()

    # Initiale config.json aufbauen
    initial_config = {
        "wifi": {
            "ssid": ssid,
            "password": wifi_pass,
            "hostname": "SignalRPI"
        },
        "mqtt": {
            "broker": "",
            "port": 1883,
            "user": None,
            "password": None,
            "client_id": "signalrpi"
        },
        "rf": {
            "mode_868": "FSK"
        }
    }
    
    # Temporäre config.json lokal schreiben
    os.makedirs("build", exist_ok=True)
    temp_config_path = os.path.join("build", "config.json")
    with open(temp_config_path, "w", encoding="utf-8") as f:
        json.dump(initial_config, f, indent=2)
    print("      Konfiguration vorbereitet.\n")

    # 3. Web-Assets aktualisieren (gzip)
    print("[3/5] Web-Dashboard komprimieren (gzip)...")
    if os.path.exists("src/index.html"):
        import gzip
        with open("src/index.html", "rb") as f_in, gzip.GzipFile("src/index.html.gz", "wb", mtime=0) as f_out:
            f_out.write(f_in.read())
        orig_sz = os.path.getsize("src/index.html")
        gz_sz = os.path.getsize("src/index.html.gz")
        print(f"      index.html: {orig_sz//1024} KB -> index.html.gz: {gz_sz//1024} KB (-{int((1 - gz_sz/orig_sz)*100)}%)\n")

    # 4. Dateien übertragen
    print("[4/5] Uebertrage Dateien auf den Raspberry Pi Pico W...")
    
    # Stoppe eventuell laufende Programme
    run_mpremote(port, ["exec", "import machine"])
    
    # Basisdateien
    files_to_copy = [
        ("src/boot.py", ":boot.py"),
        ("src/main.py", ":main.py"),
        ("src/config_loader.py", ":config_loader.py"),
        ("src/cc1101.py", ":cc1101.py"),
        ("src/pio_receiver.py", ":pio_receiver.py"),
        ("src/device_manager.py", ":device_manager.py"),
        ("src/web_server.py", ":web_server.py"),
        ("src/time_sync.py", ":time_sync.py"),
        ("src/ota_updater.py", ":ota_updater.py"),
        ("src/index.html.gz", ":index.html.gz"),
        (temp_config_path, ":config.json"),
    ]
    
    for src, dst in files_to_copy:
        if os.path.exists(src):
            print(f"      -> {os.path.basename(src)}")
            ok, out, err = run_mpremote(port, ["fs", "cp", src, dst])
            if not ok:
                print(f"         Warnung bei {src}: {err.strip()}")

    # Ordner en_decoders
    print("      -> Ordner en_decoders/")
    run_mpremote(port, ["fs", "mkdir", ":en_decoders"])
    for dec_file in glob.glob("src/en_decoders/*.py"):
        base = os.path.basename(dec_file)
        run_mpremote(port, ["fs", "cp", dec_file, f":en_decoders/{base}"])

    # Ordner lib
    print("      -> Ordner lib/")
    run_mpremote(port, ["fs", "mkdir", ":lib"])
    run_mpremote(port, ["fs", "mkdir", ":lib/umqtt"])
    if os.path.exists("src/lib/umqtt/simple.py"):
        run_mpremote(port, ["fs", "cp", "src/lib/umqtt/simple.py", ":lib/umqtt/simple.py"])
    if os.path.exists("src/lib/ssl.mpy"):
        run_mpremote(port, ["fs", "cp", "src/lib/ssl.mpy", ":lib/ssl.mpy"])
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

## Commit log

2026-06-24 feat: implement CC1101 driver for continuous ASK/OOK reception
2026-09-14 docs: add fritzing schematic
    [signalrpi.fzz]
2026-09-14 doc:add 3D model for housing with parts
    [Pico-R3.step, ebyte_e07-m1101d-sma.step, module_CC1101_t.step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]
2026-09-18 fix: continue housing cad and add orcafiles
    [Gehaeuse.3mf, signalrpi-gehaeuse-Deckel.step, signalrpi-gehaeuse-Gehaeuse.step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]
2026-09-19 chore: rework details in cad model
    [Gehaeuse.3mf, signalrpi-gehaeuse-Deckel.step, signalrpi-gehaeuse-Gehaeuse.step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]
2026-09-19 docs & hw: Pinbelegung auf getrennte SPI-Busse (SPI1/SPI0) und Pufferkondensator-Konzept umgestellt
2026-09-19 doc: fix schematics
    [signalrpi.fzz]
2026-09-19 feat: Asynchrones Web-Dashboard, REST-API, Live-Sniffer und Home Assistant Auto-Discovery integriert
2026-09-19 feat(web): Sniffer Zeitstempel, Sensor-Details und Re-Assignment für Batteriewechsel hinzugefügt
2026-09-19 feat: Live-Messwertanzeige auf den Gerätekacheln und robuster String/Int ID-Abgleich
2026-09-19 feat(ui): Grüner Badge im Sniffer wenn Paket einem bekannten Sensor zugeordnet ist
2026-09-19 fix(pio): korrigiere PIO wrap Direktive in pio_receiver
    [pio_receiver.py]
2026-09-19 feat(web): Rohdaten-Inspektor und Export für unbekannte HF-Signale integriert
2026-09-19 feat: generische Sensor-Konfiguration, MQTT-Freigabe Toggle und duales OTA-System (GitHub & Web-Upload)
2026-09-19 fix(web): Anzeige der Messwerte korrigiert (d.latest und Zeitstempel-Feld)
    [device_manager.py]
2026-09-19 fix(ram): Puffer-Begrenzung in pio_receiver gegen MemoryError bei HF-Rauschen und periodische GC
    [main.py, pio_receiver.py]
2026-09-20 feat(led): import gc gefixt und Onboard-LED Pulse bei Paketempfang integriert
2026-09-20 fix(mqtt): Drosselung für HA Discovery gegen ECONNRESET, entities-weites remove_discovery und kontrastreicher Toggle-Button
    [device_manager.py]
2026-09-20 feat(ui): Kachel-Layout mit transparent-grünem MQTT-Badge oben und Funktionsleiste (Typ-Auswahl, Aktivieren/Inaktivieren, Löschen) unten
2026-09-20 UI: Button-Beschriftung auf MQTT registrieren/deregistrieren angepasst
2026-09-20 Fix: Router-Reihenfolge in web_server.py fuer toggle und profile korrigiert
    [web_server.py]
2026-09-20 Netzwerk: Hostname SignalRPI konfiguriert; Backup/Download fuer devices.json integriert
2026-09-20 System: Upload & Restore fuer devices.json mit Sofort-Reload integriert
2026-09-20 UI: Reihenfolge der System-Kacheln auf 1. GitHub, 2. Firmware-Datei, 3. Config angepasst
2026-09-20 UI: Channel und forced_send aus Messwert-Grid filtern
2026-09-20 Feature: NTP-Zeitsynchronisation mit Zeitzonen-Konfiguration und EU-Sommerzeit
2026-09-20 UI: Titel auf 'Bekannte Funk-Geräte' gekürzt und obsoleten Button entfernt
2026-09-20 Refine Intertechno V3 buttons to Anlegen and Anlernen, add full string parser for 26-bit code and channel
2026-09-20 Harmonize Intertechno V1 form and buttons with V3 layout
2026-09-20 Replace blocking browser alerts with floating toast notifications and optimize RAM before webserver boot
    [main.py]
2026-09-20 feat(ui,tx): 2-stufiger MQTT-Workflow, Edit-Modus und TX-Stabilitätsfixes
    - Zweistufige MQTT-Registrierung für Home Assistant via Button
    - Klick auf Gerätekachel öffnet Konfiguration/Bearbeitung (IT & Sensoren)
    - Behebung des PIO State Machine Deadlocks nach TX
    - Entfernung von disable_irq() in CC1101 TX zum Schutz des CYW43 WLAN-Treibers
    - Socket-Timeouts im Webserver und entzerrtes Frontend-Polling
    - Aktualisierte Gehäuse-CAD-Dateien
    [Gehaeuse.3mf, signalrpi-gehaeuse-Deckel mit Loch.step, signalrpi-gehaeuse.FCStd]
2026-09-20 fix(cc1101): PATABLE und FREND0 für +10 dBm OOK Sendeleistung konfiguriert
    [cc1101.py]
2026-09-20 fix(it_encoder): exakte FHEM 10_IT.pm Drehschalter Tri-State Tabelle und 380us Basiszeit implementiert
2026-09-20 feat: SignalDUINO Pattern-Decoder und Intertechno V1/V3 Protokoll-Decoder integriert
2026-09-20 docs: SignalDUINO Mustererkennung und Intertechno V1/V3 in README dokumentiert
2026-09-20 refactor: CUL-Präfix von TCM97001 entfernt und PatternDecoder integriert
2026-09-20 feat: SD_WS_50 auf SignalDUINO PatternDecoder umgestellt und sd_ws07 bereinigt
2026-09-20 fix: Glitch-Filter korrigiert, SD_WS07/Nexus implementiert und TCM97001 erweitert
    [ota_updater.py, pio_receiver.py]
2026-09-20 fix: pio_receiver und tcm97001 auf sauberen Originalstand zurueckgesetzt
    [pio_receiver.py]
2026-09-20 fix: Timeout auf 10ms erhoeht und Pipeline auf IT und TCM97001 fokussiert
    [pio_receiver.py]
2026-09-20 feat: Schalter (switch) und Fernbedienung (button) Profile ergaenzt und Sniffer-Badge Erkennung optimiert
2026-09-20 feat: Switch State Tracking bei eingehenden Funkbefehlen (Fernbedienungen) integriert
2026-09-20 fix: Schnelle Direkt-Dekodierung fuer TCM97001 priorisiert und HA-ID Umbenennung integriert
2026-09-20 refactor: Einzelnes Gerätenamensfeld mit automatischer Sonderzeichenbereinigung für signalrpi und HA
2026-09-21 fix: PIO-Timeout auf 5ms zurueckgesetzt, Puffer auf 250 Flanken
    pause_threshold_us: 10000 -> 5000 us: TCM97001-Sync (~9ms) loest
    sauber das Paketende aus. Mit 10ms war der Sync kein Timeout mehr.
    Pufferlimit: 160 -> 250 Flanken: TCM97001-Pakete (36 Bit) koennen
    nah an 80 Werte gehen, mit 160 wurden sie mittendrin verworfen.
    [pio_receiver.py]
2026-09-21 feat: CC1101-RSSI als Messwert im Sensor-State-Payload
    RSSI des 433-MHz-Empfaengers wird beim Publish auf den HA-State-Topic
    als Feld 'rssi' (dBm) mitgeschickt. Nur fuer Sensor-Geraete, nicht
    fuer Schalter.
2026-09-21 fix: HA MQTT Discovery repariert (3 Aenderungen)
    1. MQTT-Payload als bytes statt str publishen (.encode('utf-8'))
    - umqtt.simple hat len(str) statt len(bytes) verwendet
    - Grad-Zeichen (°C) ist 2 Bytes, 1 Zeichen -> MQTT-Paket korrupt
    - Mosquitto hat Temperatur-Discovery still verworfen
    2. state_class: measurement fuer numerische device_class ergaenzt
    - HA 2023+ erwartet state_class fuer temperature, humidity etc.
    - Ohne state_class werden Sensoren nicht korrekt kategorisiert
    3. RSSI-Entity in thermo_hygro und thermo Profil aufgenommen
    - unit: dBm, device_class: signal_strength, icon: mdi:signal
    [device_manager.py]
2026-09-21 doce: gehaeusedeckel mit bohrung ergaenzt
    [signalrpi-gehaeuse.FCStd]
2026-09-22 fix: rim of the housing corrected
    [Gehaeuse.3mf, signalrpi-gehaeuse-Deckel mit Loch.step, signalrpi-gehaeuse-Deckel.step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]
2026-09-22 fix(cc1101): fix FSK PKTCTRL1 and FIFO threshold for WH51/WH40 sensors
    [cc1101.py, main.py, web_server.py]
2026-09-22 fix(ota): include index.html in OTA updater and sync static_html.py
    [ota_updater.py]
2026-09-22 fix: 868 MHz Frequenz 868.35->868.30 MHz (WH51/WH40), ADC-Bitmaske korrigiert, Debug-Print fuer FSK-Pakete
    [main.py]
2026-09-22 fix: CC1101 MDMCFG4 0x5A->0x59 (DRATE_E 10->9), Symbolrate 34.52->17.26 kBaud fuer WH51/WH40
    [cc1101.py]
2026-09-22 fix: 868 MHz FSK AGC auf maximale Empfindlichkeit (AGCCTRL2=0x07, MAGN_TARGET=42dB)
    [cc1101.py]
2026-09-22 fix: CC1101 868 MHz exakt an sduinoESP Fine_Offset_WH51_868 anpassen (868.35 MHz, BW=135 kHz, AGC=0x43/0x68, FSCTRL1=0x06)
    [cc1101.py, main.py]
2026-09-23 fix: SMPS PWM mode on GPIO23 and SPI baudrate 1MHz
    [Gehaeuse.3mf]
2026-09-23 fix(868MHz): set 868.30MHz carrier, add GDO0 sync and WH51/WH40 packet filter, add sniffer toggle
    [cc1101.py, main.py]
2026-09-23 fix(868): activate Carrier Sense qualifier (MDMCFG2=0x12), 200kHz filter BW (MDMCFG4=0x89) and remove blocking GDO0 read
    [cc1101.py]
2026-09-23 fix(sniffer): filter sub -88dBm unparsed FSK noise from web sniffer queue
    [Gehaeuse.3mf, signalrpi-gehaeuse-Deckel.step, signalrpi-gehaeuse-Gehaeuse.step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]
2026-09-23 doc: cad files for housing for one module with sma antenna and the other for 868 with spiral antenna
    [Gehaeuse.3mf, signalrpi-gehaeuse-Deckel mit Loch.step, signalrpi-gehaeuse-Deckel.step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]
2026-09-23 feat: add rain and moisture profiles with 0.1mm resolution and total_increasing HA discovery
2026-09-23 UI: Clean header badges, fix IT V1/V3 edit switching and remove dropdown brackets
2026-09-23 UI: Add device grouping (protocol/profile/mqtt) and sorting; improve IT subtab switching
2026-09-23 Refactor decoders to en_decoders, integrate encoders, clean root index.html and update UI profiles
2026-09-23 Support light device profile for Home Assistant and fix MQTT command processing
    [device_manager.py, main.py]
2026-09-23 fix: Geister-Entitaeten in HA nach Profilwechsel (switch->light) durch cleanup in publish_all_discovery
    [device_manager.py]
2026-09-23 fix: bei Discovery switch/light-Wechsel nur das komplementaere Topic loeschen, nicht alle Geraete
    [device_manager.py]
2026-09-23 fix: MQTT State nach Web-UI IT-Schaltbefehl publishen; light-Typ bei RF-Empfang abdecken
    [main.py, web_server.py]
2026-09-23 fix: async yield nach TX damit CYW43/WLAN sich erholt bevor MQTT publish
    [web_server.py]
2026-09-23 fix: await durch time.sleep_ms ersetzen (await im Response-Pfad riskant)
    [web_server.py]
2026-09-24 fix: robustes MQTT Reconnect/Discovery, 433MHz Serial-Log und RSSI fuer Sensoren
    [device_manager.py, main.py, web_server.py]
2026-09-24 feat: Installer install.py, Gzip-Webinterface, config.json und MQTT-Settings im Web-Dashboard
2026-09-24 docs: Installationsvorgang von fabrikneuem Pico W bis Webif ausfuehrlich dokumentiert
2026-09-24 docs: Veralteten Workflow-Abschnitt 5 entfernt und Kapitelnummerierung bereinigt
2026-09-24 feat: SignalDUINO MS-Musteranalyse, getrennte High/Low-Bins und branch-faehiges OTA
2026-09-24 feat(ota): Unterstuetzung fuer beliebige Branches via HTTP und MQTT
2026-09-24 feat(ui): Anzeige von Version und Branch im WebIF sowie Branch-Auswahl fuer OTA
2026-09-24 fix(ota): index.html.gz in Update-Liste aufgenommen und Binaer-Download unterstuetzt
    [ota_updater.py]
2026-09-24 chore(ota): index.html und static_html.py aus OTA-Liste entfernt
2026-09-24 feat(sniffer): live display of MS pattern string, glitch filtering, and fix copy buttons
    [main.py, pio_receiver.py]
2026-09-24 fix(sniffer): always include raw pulse array in sniffer events
    [main.py]
2026-09-24 fix(ui): remove redundant MS copy button in raw modal
2026-09-24 fix(reassign): improve candidate filtering in reassign modal
2026-09-24 fix(ota): remove f-strings for MicroPython compatibility and add branch to dropdown
    [ota_updater.py]
2026-09-24 fix(ota): restore cleanup_obsolete_files and add fatal exception handler
    [ota_updater.py]
2026-09-24 fix(ota): stream files in 1KB binary chunks to flash to eliminate ENOMEM
    [ota_updater.py]
2026-09-24 fix(ota): immediately reset ota_state on start and filter stale errors in polling
    [web_server.py]
2026-09-24 refactor(ota): remove polling overhead and simplify update flow
2026-09-24 fix(ui): do not overwrite target branch input with current branch in updateSystem
2026-09-24 fix(ota): suspend radio loop during OTA and clarify branch dropdown UI
    [main.py, ota_updater.py]
2026-09-24 fix(ota): ensure raw socket closure to prevent ENOMEM on subsequent files
    [ota_updater.py]
